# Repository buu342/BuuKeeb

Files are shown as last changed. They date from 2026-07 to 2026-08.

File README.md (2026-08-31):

# BuuKeeb



I've been wanting a decent mechanical keyboard for a while but I've been having a hard time finding something which fit into all of these categories:
- 100% (105 keys)
- ISO Enter
- [QMK](https://qmk.fm/) support
- LED indicators for Caps Lock, Numlock, and Scroll Lock (This one apparently is really difficult to find despite being standard in keyboards for centuries!)

I saw a Glorious PC GMMK Barebones Keyboard for 30€ which seemed to check all of these boxes (including per-key RGB which is a nice to have), but unfortunately the PCB revision I received had a crappy 8-bit MCU, which meant that writing QMK support for it would be infeasible. The case it came with was mostly metal and pretty nice however, so I decided to make a clone of the PCB, but with an STM32. This would also serve as a cool hardware design learning experience for me!

The BuuKeeb™®© features:
- 105 keys with ISO enter for the 0.01% population of the world who types on a Portuguese layout.
- Hotswappable MX switches.
- N-Key Rollover.
- Per Key LEDs on the north side, individually addressible. [OpenRGB](https://openrgb.org/) support. Key colors savable to persistent storage.
- STM32 MCU for QMK support.
- LED indicators for Caps Lock, Numlock, and Scroll Lock (incredible feature, I know).
- My face on the keyboard for added narcissism.
- Functional. Definitely.

### Keyboard Macros:

* **Alt GR + ESC** - Clear the EEPROM
* **Alt GR + F1** - Decrease the screen brightness
* **Alt GR + F2** - Increase the screen brightness
* **Alt GR + F3** - Projection mode (Windows + P)
* **Alt GR + F4** - Open search bar
* **Alt GR + F5** - Previous track
* **Alt GR + F6** - Pause/Play
* **Alt GR + F7** - Next track
* **Alt GR + F8** - Mute
* **Alt GR + F9** - Decrease volume
* **Alt GR + F10** - Increase volume
* **Alt GR + F11** - Decrease backlight brightness
* **Alt GR + F12** - Increase backlight brightness
* **Alt GR + PrntScr** - Mute microphone
* **Alt GR + ScrLck** - Eject disk
* **Alt GR + Pause** - Suspend/Sleep PC
* **CTRL + Alt GR + ESC** - Save OpenRGB Direct Mode colors to persistent memory

### Editing in KiCad

The design uses [marbastlib](https://github.com/ebastler/marbastlib) for some components so make sure you have that installed before opening the project in KiCad.

### Ordering

The `production` folder provides all the files you need for JLCPCB. You can zip up the entire folder and feed it to JLC. 

During the BOM selection, you can refer to the `bom-JLCPCB Assembly Order.xls` file to look at what components I used when I ordered my PCBs.

### Compiling the QMK Firmware:

1. Download the [OpenRGB QMK Community Module](https://gitlab.com/OpenRGBDevelopers/QMK-OpenRGB) repository.
2. Place it inside the `qmk_firmware/modules` folder and rename it to `openrgb`
3. If your copy of the qmk firmware does not ship with a `buukeeb` folder inside the `qmk_firmware/keyboards` folder, copy the QMK folder from my repository and put it inside the `qmk_firmware/keyboards`, renaming it to `buukeeb` (alternatively place a symbolic link instead).
4. Compile the firmware using your preferred method. I am on Linux so I used `qmk compile -kb buukeeb -km default`.
5. To flash the keyboard, hold down the BOOT button on the back of the board (above the 3 status indicator LEDs) and plug it into the PC. You can then let go of the button and flash it using your preferred method. I am on Linux so I used `qmk flash -kb buukeeb -km default`. 

### Special Thanks:

- [BigBass](https://github.com/bigbass1997) for helping me out with a bunch of KiCad questions and reviewing my PCB designs.
- [Keyboard Atelier Discord community](https://kbatelier.org/) for helping me and doing a keyboard review. Specific shoutouts to Quark, Indeed, Moo, The Great Advisor Xaetral™, Sune, and SenseiZéッ for answering general questions. Another big thanks to cadiremar, galile0, Jubakuba, and SenseiZéッ for the keyboard review.
- [QMK Discord community](https://discord.gg/qmk) for helping me bugfix. Specific shoutout to Drashna Jael're for identifying the LED bug.
- [OpenRGB Discord community](https://discord.gg/AQwjJPY) for answering some OpenRGB questions. Specific shoutout to CalcProgrammer1 for answering my questions.

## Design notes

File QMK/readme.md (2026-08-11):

# buukeeb

buukeeb

*A short description of the keyboard/project*

* Keyboard Maintainer: [Lourenço Soares](https://github.com/Buu342)
* Hardware Supported: *The PCBs, controllers supported*
* Hardware Availability: *Links to where you can find this hardware*

Make example for this keyboard (after setting up your build environment):

    make buukeeb:default

Flashing example for this keyboard:

    make buukeeb:default:flash

See the [build environment setup](https://docs.qmk.fm/#/getting_started_build_tools) and the [make instructions](https://docs.qmk.fm/#/getting_started_make_guide) for more information. Brand new to QMK? Start with our [Complete Newbs Guide](https://docs.qmk.fm/#/newbs).

## Bootloader

Enter the bootloader in 3 ways:

* **Bootmagic reset**: Hold down the key at (0,0) in the matrix (usually the top left key or Escape) and plug in the keyboard
* **Physical reset button**: Briefly press the button on the back of the PCB - some may have pads you must short instead
* **Keycode in layout**: Press the key mapped to `QK_BOOT` if it is available

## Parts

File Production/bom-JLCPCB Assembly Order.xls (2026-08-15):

JLCPCB BOM Tool - BOM Matching
BOM name：bom-JLCPCB Assembly Order.xlsx |  |  | Download Time：2026-07-28 05:34:23 |  |  |  | * Our matching results are updated in real-time, but stock and prices may change. If it's been over 24 hours, please re-match before placing your order.
PCB Assembled Qty：5 |  |  | Est. Total Price：35.7558
Your BOM |  |  |  |  | Matched Parts |  |  |  |  |  |  | Order Information
Top Designator | Bottom Designator | Comment | Footprint | JLCPCB Part # | Matches | Part # | Manufacturer | Footprint | Description | Category | Warning | JLCPCB Part # | Product link | Lib Type | Qty | Source | Total Price ($)
 | C1,C10,C100,C101,C102,C103,C104,C105,C106,C107,C108,C109,C11,C110,C111,C112,C113,C114,C115,C116,C117,C118,C12,C13,C14,C15,C16,C17,C18,C19,C2,C20,C21,C22,C23,C24,C25,C26,C27,C28,C29,C3,C30,C31,C32,C33,C34,C35,C36,C37,C38,C39,C4,C40,C41,C42,C43,C44,C45,C46,C47,C48,C49,C5,C50,C51,C52,C53,C54,C55,C56,C57,C58,C59,C6,C60,C61,C62,C63,C64,C65,C66,C67,C68,C69,C70,C71,C72,C73,C74,C75,C76,C77,C78,C79,C80,C81,C82,C83,C84,C85,C86,C87,C88,C89,C90,C91,C92,C93,C94,C95,C96,C97,C98,C99 | 100nF | 0402 |  | Select by System | CL05B104KO5NNNC | Samsung Electro-Mechanics | 0402 | 100nF 16V X7R ±10% 0402 Multilayer Ceramic Capacitors MLCC - SMD/SMT ROHS | Multilayer Ceramic Capacitors MLCC - SMD/SMT |  | C1525 | https://jlcpcb.com/partdetail/1877-CL05B104KO5NNNC/C1525 | Basic | 240 | 240 JLCPCB | 1.272
 | C7 | 10uF | 0603 |  | Select by System | CL10A106KP8NNNC | Samsung Electro-Mechanics | 0603 | 10V 10uF X5R ±10% 0603 Multilayer Ceramic Capacitors MLCC - SMD/SMT ROHS | Multilayer Ceramic Capacitors MLCC - SMD/SMT |  | C19702 | https://jlcpcb.com/partdetail/20411-CL10A106KP8NNNC/C19702 | Basic | 20 | 20 JLCPCB | 0.816
 | C8,C9 | 1uF | 0402 |  | Select by System | CL05A105KA5NQNC | Samsung Electro-Mechanics | 0402 | 1uF 25V X5R ±10% 0402 Multilayer Ceramic Capacitors MLCC - SMD/SMT ROHS | Multilayer Ceramic Capacitors MLCC - SMD/SMT |  | C52923 | https://jlcpcb.com/partdetail/53938-CL05A105KA5NQNC/C52923 | Basic | 20 | 20 JLCPCB | 0.53
 | C119 | 4.7uF | 0603 |  | Select by System | CL10A475KO8NNNC | Samsung Electro-Mechanics | 0603 | 16V 4.7uF X5R ±10% 0603 Multilayer Ceramic Capacitors MLCC - SMD/SMT ROHS | Multilayer Ceramic Capacitors MLCC - SMD/SMT |  | C19666 | https://jlcpcb.com/partdetail/20375-CL10A475KO8NNNC/C19666 | Basic | 20 | 20 JLCPCB | 0.73
 | D1,D10,D100,D101,D102,D103,D104,D105,D11,D12,D13,D14,D15,D16,D17,D18,D19,D2,D20,D21,D22,D23,D24,D25,D26,D27,D28,D29,D3,D30,D31,D32,D33,D34,D35,D36,D37,D38,D39,D4,D40,D41,D42,D43,D44,D45,D46,D47,D48,D49,D5,D50,D51,D52,D53,D54,D55,D56,D57,D58,D59,D6,D60,D61,D62,D63,D64,D65,D66,D67,D68,D69,D7,D70,D71,D72,D73,D74,D75,D76,D77,D78,D79,D8,D80,D81,D82,D83,D84,D85,D86,D87,D88,D89,D9,D90,D91,D92,D93,D94,D95,D96,D97,D98,D99 | D | D_SOD-123 |  | Select by Customer | 1N4148SOD-123 | Shenzhen Jinkaisheng Elec | SOD-123 | -65℃~+150℃@(Tj) 150mA 1V@10mA 2A 400mW 4ns 5uA@75V 75V Independent SOD-123 Switching Diodes ROHS | Switching Diodes |  | C2972760 | https://jlcpcb.com/partdetail/3368026-1N4148SOD123/C2972760 | Extended | 220 | 220 JLCPCB | 2.794
 | F1 | 500mA | 1206 |  | Select by System | BSMD1206-050-33V | BHFUSE | 1206 | -40℃~+85℃ 1.9mm 150mΩ 1A 1mm 3.6mm 33V 40A 500mA 800mW 850mΩ 1206 Resettable Fuses ROHS | Resettable Fuses |  | C7202014 | https://jlcpcb.com/partdetail/BHFUSE-BSMD1206_05033V/C7202014 | Extended | 6 | 6 JLCPCB | 0.4116
 | J2 | Conn_01x05_Pin | PinHeader_1x05_P2.00mm_Horizontal |  | Select by Customer | PZ200-1-05-W-2.0-G1 | HCTL | 弯插,P=2mm | -40℃~+105℃ 1 1.5A 1x5P 2mm 2mm 4mm 5P Black Brass Gold Pin Header Right Angle Push-Pull,P=2mm Pin Headers ROHS | Pin Headers |  | C19270575 | https://jlcpcb.com/partdetail/HCTL-PZ200_1_05_W_2_0G1/C19270575 | Extended | 2 | 2 JLCPCB | 0.1626
 | LED1,LED10,LED100,LED101,LED102,LED103,LED104,LED105,LED106,LED107,LED108,LED11,LED12,LED13,LED14,LED15,LED16,LED17,LED18,LED19,LED2,LED20,LED21,LED22,LED23,LED24,LED25,LED26,LED27,LED28,LED29,LED3,LED30,LED31,LED32,LED33,LED34,LED35,LED36,LED37,LED38,LED39,LED4,LED40,LED41,LED42,LED43,LED44,LED45,LED46,LED47,LED48,LED49,LED5,LED50,LED51,LED52,LED53,LED54,LED55,LED56,LED57,LED58,LED59,LED6,LED60,LED61,LED62,LED63,LED64,LED65,LED66,LED67,LED68,LED69,LED7,LED70,LED71,LED72,LED73,LED74,LED75,LED76,LED77,LED78,LED79,LED8,LED80,LED81,LED82,LED83,LED84,LED85,LED86,LED87,LED88,LED89,LED9,LED90,LED91,LED92,LED93,LED94,LED95,LED96,LED97,LED98,LED99 | SK6812MINI-E | LED_6028R_NoHoles |  | Select by System | SK6812MINI-E | OPSCO Optoelectronics | SMD | -40℃~+85℃ 0.6mA 1.78mm 120° 1kHz 2.8mm 2000V 3.2mm 3.7V~5.5V 800Kbit/s G:815mcd~1275mcd、B:120mcd~240mcd、R:160mcd~320mcd R:620nm~625nm、G:515nm~525nm、B:460nm~470nm Semi-transparent lens SMD RGB LEDs(Built-in IC) ROHS | RGB LEDs(Built-In IC) |  | C5149201 | https://jlcpcb.com/partdetail/OPSCOOptoelectronics-SK6812MINIE/C5149201 | Extended | 218 | 218 JLCPCB | 13.08
 | MX1,MX10,MX100,MX101,MX102,MX103,MX104,MX105,MX11,MX12,MX13,MX14,MX15,MX16,MX17,MX18,MX19,MX2,MX20,MX21,MX22,MX23,MX24,MX25,MX26,MX27,MX28,MX29,MX3,MX30,MX31,MX32,MX33,MX34,MX35,MX36,MX37,MX38,MX39,MX4,MX40,MX41,MX42,MX43,MX44,MX45,MX46,MX47,MX48,MX49,MX5,MX50,MX51,MX52,MX53,MX54,MX55,MX56,MX57,MX58,MX59,MX6,MX60,MX61,MX62,MX63,MX64,MX65,MX66,MX67,MX68,MX69,MX7,MX70,MX71,MX72,MX73,MX74,MX75,MX76,MX77,MX78,MX79,MX8,MX80,MX81,MX82,MX83,MX84,MX85,MX86,MX87,MX88,MX89,MX9,MX90,MX91,MX92,MX93,MX94,MX95,MX96,MX97,MX98,MX99 | MX_SW_HS | SW_MX_HS_CPG151101S11_1.5u_NoHoles |  | Select by Customer | CPG151101S11-2 | HanElectricity | - | 12V 2 3000gf 5,000 cycles - Mechanical Keyboard Shaft ROHS |  |  | C49352235 | https://jlcpcb.com/partdetail/HanElectricity-CPG151101S112/C49352235 | Extended | 210 | 210 JLCPCB | 7.602
 | R1,R4 | 5.1k | 0402 |  | Unconfirmed | 0402WGF5101TCE | UNI-ROYAL(Uniroyal Elec) | 0402 | -55℃~+155℃ 5.1kΩ 50V 62.5mW Thick Film Resistor ±1% ±100ppm/℃ 0402 Chip Resistor - Surface Mount ROHS | Chip Resistor - Surface Mount | 1.The comment (0402WGF5101TCE) of this part does not match the one (5.1k) provided in your BOM. Please confirm; | C25905 | https://jlcpcb.com/partdetail/26648-0402WGF5101TCE/C25905 | Basic | 20 | 20 JLCPCB | 0.134
 | R2 | 470 | 0402 |  | Unconfirmed | 0402WGF4700TCE | UNI-ROYAL(Uniroyal Elec) | 0402 | -55℃~+155℃ 470Ω 50V 62.5mW Thick Film Resistor ±1% ±100ppm/℃ 0402 Chip Resistor - Surface Mount ROHS | Chip Resistor - Surface Mount | 1.The comment (0402WGF4700TCE) of this part does not match the one (470) provided in your BOM. Please confirm; | C25117 | https://jlcpcb.com/partdetail/25860-0402WGF4700TCE/C25117 | Basic | 20 | 20 JLCPCB | 0.154
 | SW1 | SW_Push | SW_SPST_TL3342 |  | Select by System | TS-1187A-B-A-B | XKB Connection | SMD-4P,5.1x5.1mm | -30℃~+85℃ 1.5mm 1.6N 100,000 cycles 12V 5.1mm 5.1mm 50mA Gold No Round Button SPST Surface Mount,Vertical Without Bracket SMD-4P,5.1x5.1mm Tactile Switches ROHS | Tactile Switches |  | C318884 | https://jlcpcb.com/partdetail/XKBConnection-TS_1187A_B_AB/C318884 | Basic | 7 | 7 JLCPCB | 0.1428
 | U1 | STM32F072C8Tx | LQFP-48_7x7mm_P0.5mm |  | Select by Customer | STM32F072C8T6 | STMicroelectronics | LQFP-48(7x7) | -40℃~+85℃ 1.65V~3.6V 12bit 12bit 16KB 32 Bit 37 48MHz 64KB ARM Cortex-M0 Built-in FLASH LQFP-48(7x7) Microcontrollers (MCU/MPU/SOC) ROHS | Microcontrollers (MCU/MPU/SOC) |  | C80488 | https://jlcpcb.com/partdetail/STMicroelectronics-STM32F072C8T6/C80488 | Extended | 2 | 2 JLCPCB | 5.0882
 | U2 | 74AHCT1G125 | TSOP-5_1.65x3.05mm_P0.95mm |  | Select by Customer | 74AHCT1G125GV | MDD(Microdiode Semiconductor) | SOT-23-5L | -40℃~+125℃ 1 1 1ns@4.5V 4.5V~5.5V 40uA 74AHCT 8mA 8mA Output enable、Level shifting Tri-State Unidirectional SOT-23-5L Buffers, Drivers, Receivers, Transceivers ROHS |  |  | C52140417 | https://jlcpcb.com/partdetail/54938146-74AHCT1G125GV/C52140417 | Extended | 6 | 6 JLCPCB | 0.3889
 | U3 | XC6206PxxxMR | SOT-23-3 |  | Select by Customer | XC6206P332MR-G | Torex Semicon | SOT-23-3L | -40℃~+85℃@(Ta) 1 1uA 200mA 3.3V 6V Fixed Over Current Protection Positive SOT-23-3L Voltage Regulators - Linear, Low Drop Out (LDO) Regulators ROHS | Voltage Regulators - Linear, Low Drop Out (LDO) Regulators |  | C5446 | https://jlcpcb.com/partdetail/TorexSemicon-XC6206P332MRG/C5446 | Basic | 5 | 5 JLCPCB | 0.663
 | U4 | USB6B1 | SOIC-8_3.9x4.9mm_P1.27mm |  | Select by Customer | USB6B1RL | STMicroelectronics | SOIC-8 | 10uA 15pF、25pF 2 25A@8/20us 5.25V 500W@8/20us 6V Bidirectional IEC 61000-4-2 TVS SOIC-8 ESD and Surge Protection (TVS/ESD) ROHS | ESD And Surge Protection (TVS/ESD) | 1.The comment (USB6B1RL) of this part does not match the one (USB6B1) provided in your BOM. Please confirm; | C10508 | https://jlcpcb.com/partdetail/STMicroelectronics-USB6B1RL/C10508 | Extended | 2 | 2 JLCPCB | 1.7478

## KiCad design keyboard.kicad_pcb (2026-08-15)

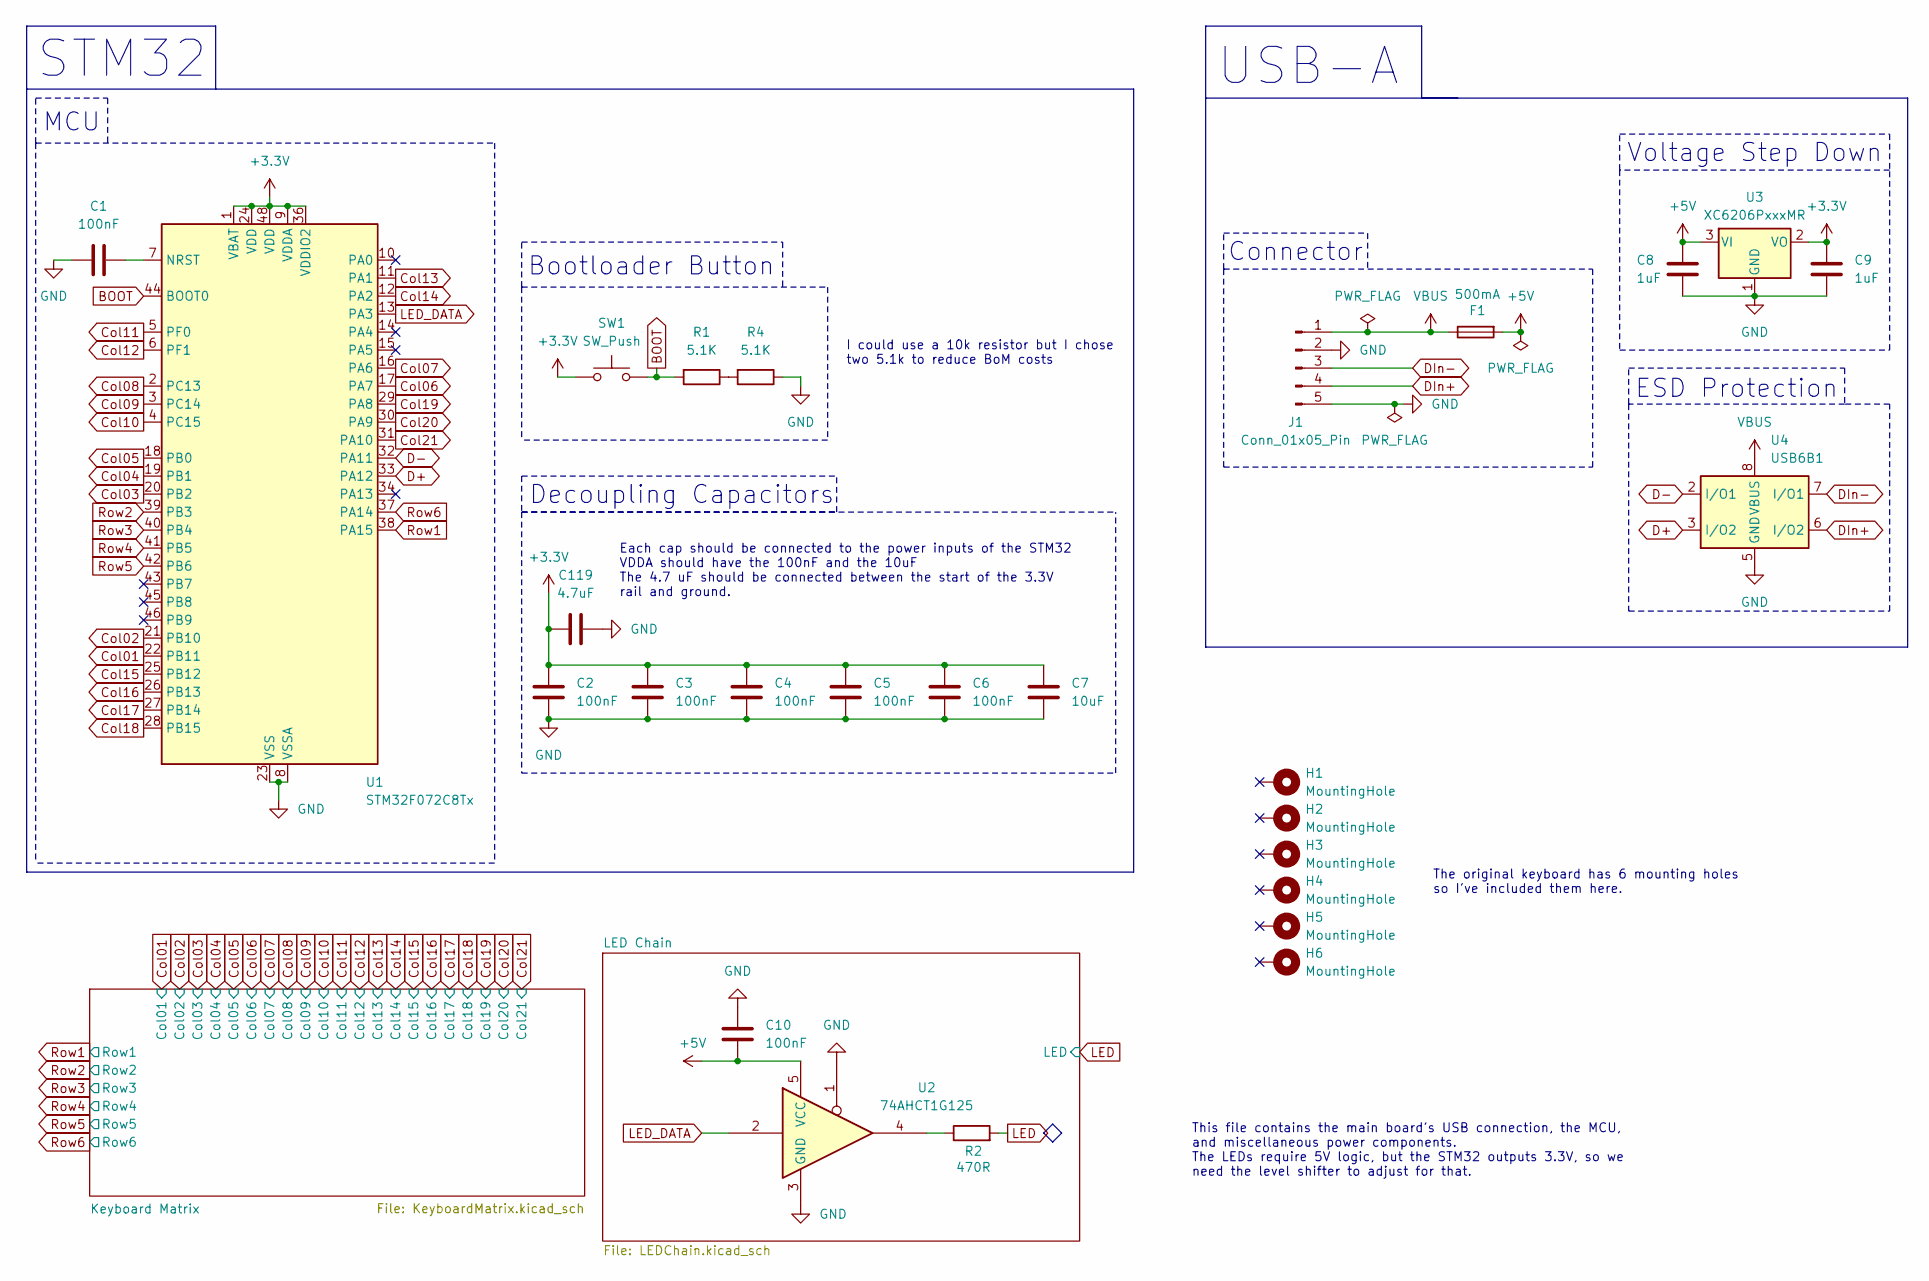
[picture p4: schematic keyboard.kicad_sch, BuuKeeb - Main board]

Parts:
C1, C2, C3, C4, C5, C6, C10: 100nF; C_0402_1005Metric
C7: 10uF; C_0603_1608Metric
C8, C9: 1uF; C_0603_1608Metric
C119: 4.7uF; C_0603_1608Metric
F1: 500mA; Fuse_1206_3216Metric
H1, H2, H3, H4, H5, H6: MountingHole; MountingHole_3.5mm_Pad_5.5mm
J1: Conn_01x05_Pin; PinHeader_1x05_P2.00mm_Horizontal
R1, R4: 5.1K; R_0402_1005Metric
R2: 470R; R_0402_1005Metric
SW1: SW_Push; SW_SPST_TL3342
U1: STM32F072C8Tx; LQFP-48_7x7mm_P0.5mm
U2: 74AHCT1G125; TSOP-5_1.65x3.05mm_P0.95mm
U3: XC6206PxxxMR; SOT-23-3
U4: USB6B1; SOIC-8_3.9x4.9mm_P1.27mm

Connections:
+3.3V: C2.1, C3.1, C4.1, C5.1, C6.1, C7.1, C9.1, C119.1, SW1.1, U1.1 (VBAT), U1.9 (VDDA), U1.24 (VDD), U1.36 (VDDIO2), U1.48 (VDD), U3.2 (VO)
+5V: C8.1, C10.2, F1.2, U2.5 (VCC), U3.3 (VI); also elsewhere on the board
BOOT: R1.2, SW1.2, U1.44 (BOOT0)
Col01: U1.22 (PB11); also elsewhere on the board
Col02: U1.21 (PB10); also elsewhere on the board
Col03: U1.20 (PB2); also elsewhere on the board
Col04: U1.19 (PB1); also elsewhere on the board
Col05: U1.18 (PB0); also elsewhere on the board
Col06: U1.17 (PA7); also elsewhere on the board
Col07: U1.16 (PA6); also elsewhere on the board
Col08: U1.2 (PC13); also elsewhere on the board
Col09: U1.3 (PC14); also elsewhere on the board
Col10: U1.4 (PC15); also elsewhere on the board
Col11: U1.5 (PF0); also elsewhere on the board
Col12: U1.6 (PF1); also elsewhere on the board
Col13: U1.11 (PA1); also elsewhere on the board
Col14: U1.12 (PA2); also elsewhere on the board
Col15: U1.25 (PB12); also elsewhere on the board
Col16: U1.26 (PB13); also elsewhere on the board
Col17: U1.27 (PB14); also elsewhere on the board
Col18: U1.28 (PB15); also elsewhere on the board
Col19: U1.29 (PA8); also elsewhere on the board
Col20: U1.30 (PA9); also elsewhere on the board
Col21: U1.31 (PA10); also elsewhere on the board
D+: U1.33 (PA12), U4.3 (I/O2)
D-: U1.32 (PA11), U4.2 (I/O1)
DIn+: J1.4, U4.6 (I/O2)
DIn-: J1.3, U4.7 (I/O1)
GND: C1.2, C2.2, C3.2, C4.2, C5.2, C6.2, C7.2, C8.2, C9.2, C10.1, C119.2, J1.2, J1.5, R4.1, U1.8 (VSSA), U1.23 (VSS), U1.35 (VSS), U1.47 (VSS), U2.1, U2.3 (GND), U3.1 (GND), U4.4 (GND), U4.5 (GND); also elsewhere on the board
LED: R2.2; also elsewhere on the board
LED_DATA: U1.13 (PA3), U2.2
unnamed: R1.1, R4.2
unnamed: R2.1, U2.4
unnamed: C1.1, U1.7 (NRST)
Row1: U1.38 (PA15); also elsewhere on the board
Row2: U1.39 (PB3); also elsewhere on the board
Row3: U1.40 (PB4); also elsewhere on the board
Row4: U1.41 (PB5); also elsewhere on the board
Row5: U1.42 (PB6); also elsewhere on the board
Row6: U1.37 (PA14); also elsewhere on the board
VBUS: F1.1, J1.1, U4.1 (VBUS), U4.8 (VBUS)

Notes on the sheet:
Connector
Voltage Step Down
MCU
The original keyboard has 6 mounting holes so I've included them here.
STM32
ESD Protection
Decoupling Capacitors
This file contains the main board's USB connection, the MCU, and miscellaneous power components. The LEDs require 5V logic, but the STM32 outputs 3.3V, so we need the level shifter to adjust for that.
I could use a 10k resistor but I chose two 5.1k to reduce BoM costs
USB-A
Bootloader Button
Each cap should be connected to the power inputs of the STM32 VDDA should have the 100nF and the 10uF The 4.7 uF should be connected between the start of the 3.3V rail and ground.

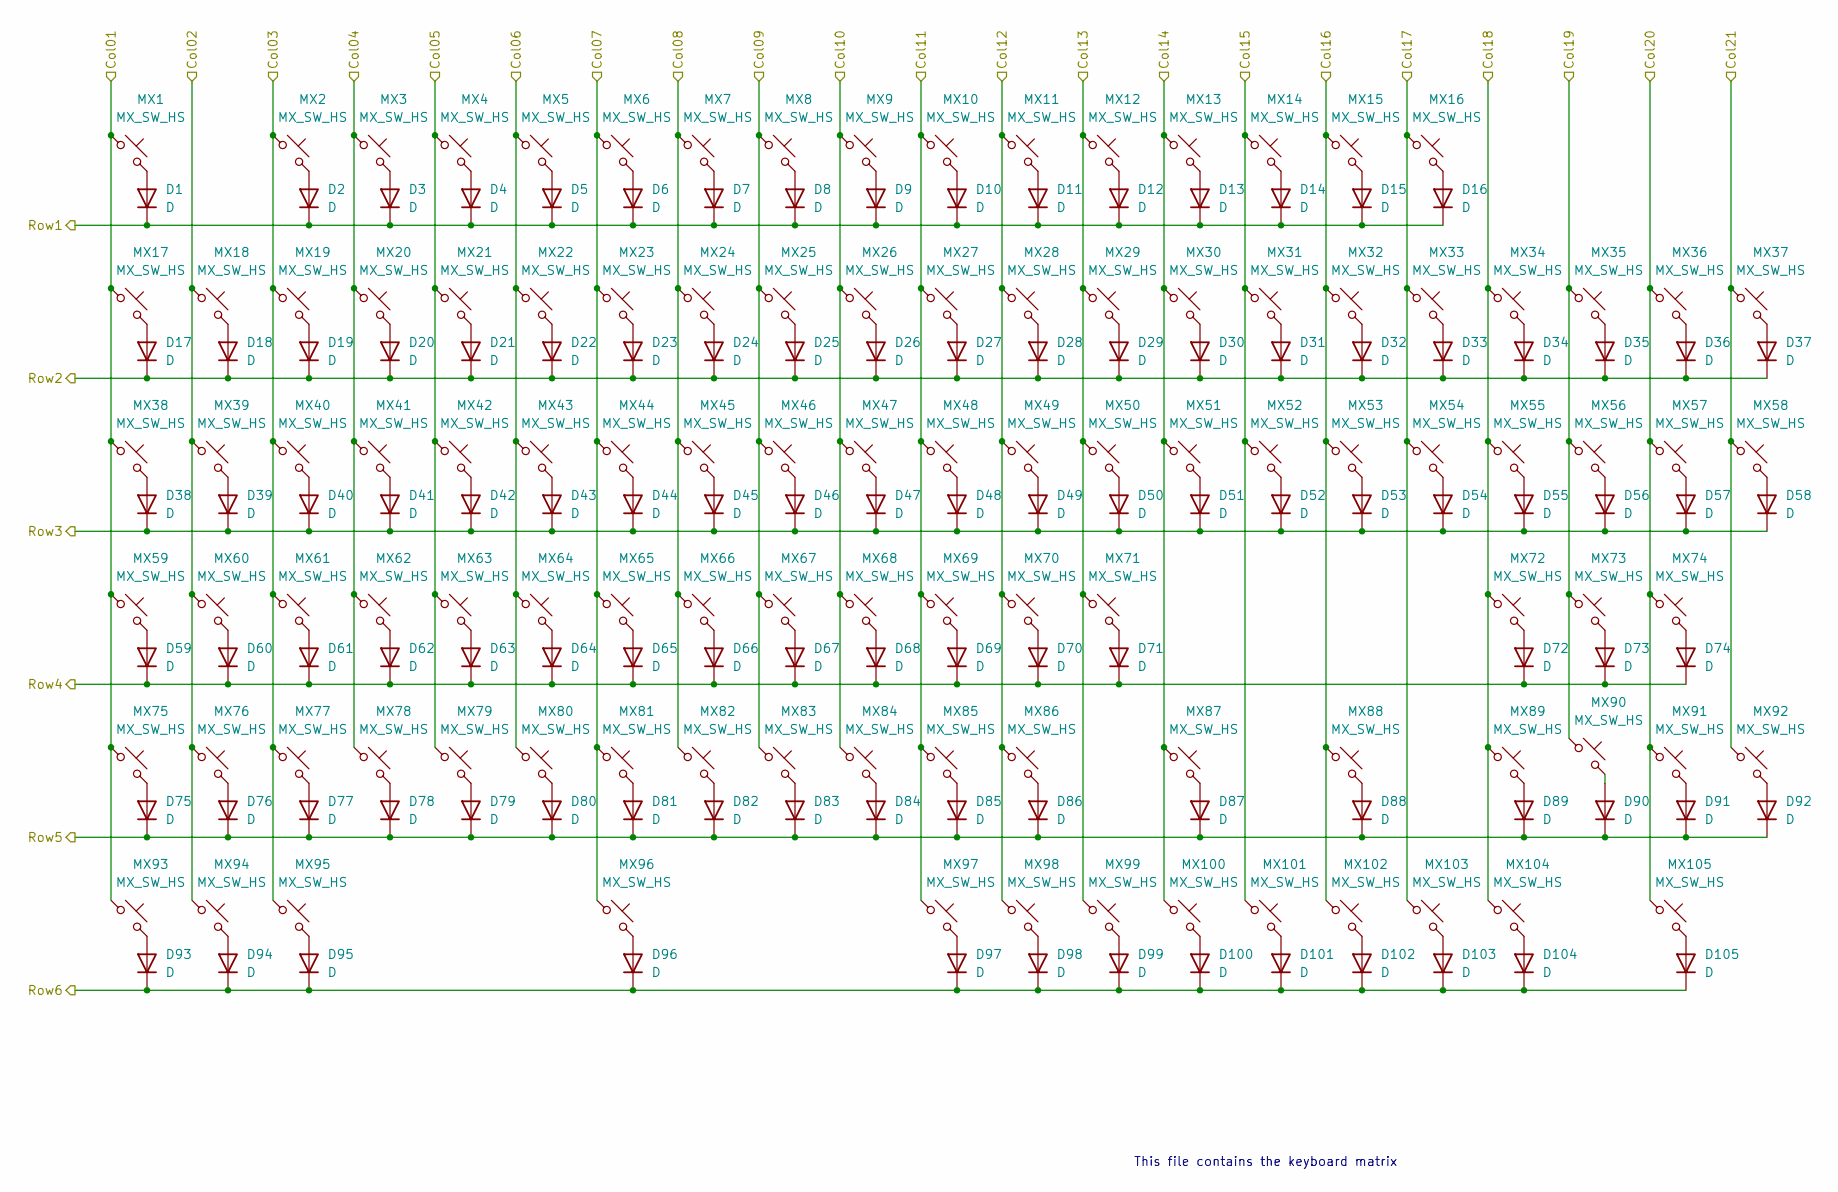
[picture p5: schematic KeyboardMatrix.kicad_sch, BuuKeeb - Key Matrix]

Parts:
D1, D2, D3, D4, D5, D6, D7, D8, D9, D10, D11, D12, D13, D14, D15, D16, D17, D18, D19, D20, D21, D22, D23, D24, D25, D26, D27, D28, D29, D30, D31, D32, D33, D34, D35, D36, D37, D38, D39, D40, D41, D42, D43, D44, D45, D46, D47, D48, D49, D50, D51, D52, D53, D54, D55, D56, D57, D58, D59, D60, D61, D62, D63, D64, D65, D66, D67, D68, D69, D70, D71, D72, D73, D74, D75, D76, D77, D78, D79, D80, D81, D82, D83, D84, D85, D86, D87, D88, D89, D90, D91, D92, D93, D94, D95, D96, D97, D98, D99, D100, D101, D102, D103, D104, D105: D; D_SOD-123
MX1, MX2, MX3, MX4, MX5, MX6, MX7, MX8, MX9, MX10, MX11, MX12, MX13, MX14, MX15, MX16, MX17, MX18, MX19, MX20, MX21, MX22, MX23, MX24, MX25, MX26, MX27, MX28, MX29, MX30, MX31, MX32, MX33, MX34, MX35, MX36, MX37, MX38, MX39, MX40, MX41, MX42, MX43, MX44, MX45, MX46, MX47, MX48, MX49, MX50, MX51, MX52, MX53, MX54, MX55, MX56, MX57, MX58, MX59, MX60, MX61, MX62, MX63, MX64, MX65, MX66, MX67, MX68, MX69, MX70, MX71, MX72, MX73, MX74, MX75, MX76, MX77, MX78, MX79, MX80, MX81, MX82, MX83, MX84, MX85, MX86, MX87, MX88, MX89, MX90, MX91, MX92, MX93, MX94, MX95, MX96, MX97, MX98, MX99, MX100, MX101, MX102, MX103, MX104, MX105: MX_SW_HS; SW_MX_HS_CPG151101S11_1.5u_NoHoles

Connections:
Col01: MX1.1, MX17.1, MX38.1, MX59.1, MX75.1, MX93.1; also elsewhere on the board
Col02: MX18.1, MX39.1, MX60.1, MX76.1, MX94.1; also elsewhere on the board
Col03: MX2.1, MX19.1, MX40.1, MX61.1, MX77.1, MX95.1; also elsewhere on the board
Col04: MX3.1, MX20.1, MX41.1, MX62.1, MX78.1; also elsewhere on the board
Col05: MX4.1, MX21.1, MX42.1, MX63.1, MX79.1; also elsewhere on the board
Col06: MX5.1, MX22.1, MX43.1, MX64.1, MX80.1; also elsewhere on the board
Col07: MX6.1, MX23.1, MX44.1, MX65.1, MX81.1, MX96.1; also elsewhere on the board
Col08: MX7.1, MX24.1, MX45.1, MX66.1, MX82.1; also elsewhere on the board
Col09: MX8.1, MX25.1, MX46.1, MX67.1, MX83.1; also elsewhere on the board
Col10: MX9.1, MX26.1, MX47.1, MX68.1, MX84.1; also elsewhere on the board
Col11: MX10.1, MX27.1, MX48.1, MX69.1, MX85.1, MX97.1; also elsewhere on the board
Col12: MX11.1, MX28.1, MX49.1, MX70.1, MX86.1, MX98.1; also elsewhere on the board
Col13: MX12.1, MX29.1, MX50.1, MX71.1, MX99.1; also elsewhere on the board
Col14: MX13.1, MX30.1, MX51.1, MX87.1, MX100.1; also elsewhere on the board
Col15: MX14.1, MX31.1, MX52.1, MX101.1; also elsewhere on the board
Col16: MX15.1, MX32.1, MX53.1, MX88.1, MX102.1; also elsewhere on the board
Col17: MX16.1, MX33.1, MX54.1, MX103.1; also elsewhere on the board
Col18: MX34.1, MX55.1, MX72.1, MX89.1, MX104.1; also elsewhere on the board
Col19: MX35.1, MX56.1, MX73.1, MX90.1; also elsewhere on the board
Col20: MX36.1, MX57.1, MX74.1, MX91.1, MX105.1; also elsewhere on the board
Col21: MX37.1, MX58.1, MX92.1; also elsewhere on the board
unnamed: D1.2 (A), MX1.2
unnamed: D2.2 (A), MX2.2
unnamed: D3.2 (A), MX3.2
unnamed: D4.2 (A), MX4.2
unnamed: D5.2 (A), MX5.2
unnamed: D6.2 (A), MX6.2
unnamed: D7.2 (A), MX7.2
unnamed: D8.2 (A), MX8.2
unnamed: D9.2 (A), MX9.2
unnamed: D10.2 (A), MX10.2
unnamed: D11.2 (A), MX11.2
unnamed: D12.2 (A), MX12.2
unnamed: D13.2 (A), MX13.2
unnamed: D14.2 (A), MX14.2
unnamed: D15.2 (A), MX15.2
unnamed: D16.2 (A), MX16.2
unnamed: D17.2 (A), MX17.2
unnamed: D18.2 (A), MX18.2
unnamed: D19.2 (A), MX19.2
unnamed: D20.2 (A), MX20.2
unnamed: D21.2 (A), MX21.2
unnamed: D22.2 (A), MX22.2
unnamed: D23.2 (A), MX23.2
unnamed: D24.2 (A), MX24.2
unnamed: D25.2 (A), MX25.2
unnamed: D26.2 (A), MX26.2
unnamed: D27.2 (A), MX27.2
unnamed: D28.2 (A), MX28.2
unnamed: D29.2 (A), MX29.2
unnamed: D30.2 (A), MX30.2
unnamed: D31.2 (A), MX31.2
unnamed: D32.2 (A), MX32.2
unnamed: D33.2 (A), MX33.2
unnamed: D34.2 (A), MX34.2
unnamed: D35.2 (A), MX35.2
unnamed: D36.2 (A), MX36.2
unnamed: D37.2 (A), MX37.2
unnamed: D38.2 (A), MX38.2
unnamed: D39.2 (A), MX39.2
unnamed: D40.2 (A), MX40.2
unnamed: D41.2 (A), MX41.2
unnamed: D42.2 (A), MX42.2
unnamed: D43.2 (A), MX43.2
unnamed: D44.2 (A), MX44.2
unnamed: D45.2 (A), MX45.2
unnamed: D46.2 (A), MX46.2
unnamed: D47.2 (A), MX47.2
unnamed: D48.2 (A), MX48.2
unnamed: D49.2 (A), MX49.2
unnamed: D50.2 (A), MX50.2
unnamed: D51.2 (A), MX51.2
unnamed: D52.2 (A), MX52.2
unnamed: D53.2 (A), MX53.2
unnamed: D54.2 (A), MX54.2
unnamed: D55.2 (A), MX55.2
unnamed: D56.2 (A), MX56.2
unnamed: D57.2 (A), MX57.2
unnamed: D58.2 (A), MX58.2
unnamed: D59.2 (A), MX59.2
unnamed: D60.2 (A), MX60.2
unnamed: D61.2 (A), MX61.2
unnamed: D62.2 (A), MX62.2
unnamed: D63.2 (A), MX63.2
unnamed: D64.2 (A), MX64.2
unnamed: D65.2 (A), MX65.2
unnamed: D66.2 (A), MX66.2
unnamed: D67.2 (A), MX67.2
unnamed: D68.2 (A), MX68.2
unnamed: D69.2 (A), MX69.2
unnamed: D70.2 (A), MX70.2
unnamed: D71.2 (A), MX71.2
unnamed: D72.2 (A), MX72.2
unnamed: D73.2 (A), MX73.2
unnamed: D74.2 (A), MX74.2
unnamed: D75.2 (A), MX75.2
unnamed: D76.2 (A), MX76.2
unnamed: D77.2 (A), MX77.2
unnamed: D78.2 (A), MX78.2
unnamed: D79.2 (A), MX79.2
unnamed: D80.2 (A), MX80.2
unnamed: D81.2 (A), MX81.2
unnamed: D82.2 (A), MX82.2
unnamed: D83.2 (A), MX83.2
unnamed: D84.2 (A), MX84.2
unnamed: D85.2 (A), MX85.2
unnamed: D86.2 (A), MX86.2
unnamed: D87.2 (A), MX87.2
unnamed: D88.2 (A), MX88.2
unnamed: D89.2 (A), MX89.2
unnamed: D90.2 (A), MX90.2
unnamed: D91.2 (A), MX91.2
unnamed: D92.2 (A), MX92.2
unnamed: D93.2 (A), MX93.2
unnamed: D94.2 (A), MX94.2
unnamed: D95.2 (A), MX95.2
unnamed: D96.2 (A), MX96.2
unnamed: D97.2 (A), MX97.2
unnamed: D98.2 (A), MX98.2
unnamed: D99.2 (A), MX99.2
unnamed: D100.2 (A), MX100.2
unnamed: D101.2 (A), MX101.2
unnamed: D102.2 (A), MX102.2
unnamed: D103.2 (A), MX103.2
unnamed: D104.2 (A), MX104.2
unnamed: D105.2 (A), MX105.2
Row1: D1.1 (K), D2.1 (K), D3.1 (K), D4.1 (K), D5.1 (K), D6.1 (K), D7.1 (K), D8.1 (K), D9.1 (K), D10.1 (K), D11.1 (K), D12.1 (K), D13.1 (K), D14.1 (K), D15.1 (K), D16.1 (K); also elsewhere on the board
Row2: D17.1 (K), D18.1 (K), D19.1 (K), D20.1 (K), D21.1 (K), D22.1 (K), D23.1 (K), D24.1 (K), D25.1 (K), D26.1 (K), D27.1 (K), D28.1 (K), D29.1 (K), D30.1 (K), D31.1 (K), D32.1 (K), D33.1 (K), D34.1 (K), D35.1 (K), D36.1 (K), D37.1 (K); also elsewhere on the board
Row3: D38.1 (K), D39.1 (K), D40.1 (K), D41.1 (K), D42.1 (K), D43.1 (K), D44.1 (K), D45.1 (K), D46.1 (K), D47.1 (K), D48.1 (K), D49.1 (K), D50.1 (K), D51.1 (K), D52.1 (K), D53.1 (K), D54.1 (K), D55.1 (K), D56.1 (K), D57.1 (K), D58.1 (K); also elsewhere on the board
Row4: D59.1 (K), D60.1 (K), D61.1 (K), D62.1 (K), D63.1 (K), D64.1 (K), D65.1 (K), D66.1 (K), D67.1 (K), D68.1 (K), D69.1 (K), D70.1 (K), D71.1 (K), D72.1 (K), D73.1 (K), D74.1 (K); also elsewhere on the board
Row5: D75.1 (K), D76.1 (K), D77.1 (K), D78.1 (K), D79.1 (K), D80.1 (K), D81.1 (K), D82.1 (K), D83.1 (K), D84.1 (K), D85.1 (K), D86.1 (K), D87.1 (K), D88.1 (K), D89.1 (K), D90.1 (K), D91.1 (K), D92.1 (K); also elsewhere on the board
Row6: D93.1 (K), D94.1 (K), D95.1 (K), D96.1 (K), D97.1 (K), D98.1 (K), D99.1 (K), D100.1 (K), D101.1 (K), D102.1 (K), D103.1 (K), D104.1 (K), D105.1 (K); also elsewhere on the board

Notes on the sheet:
This file contains the keyboard matrix

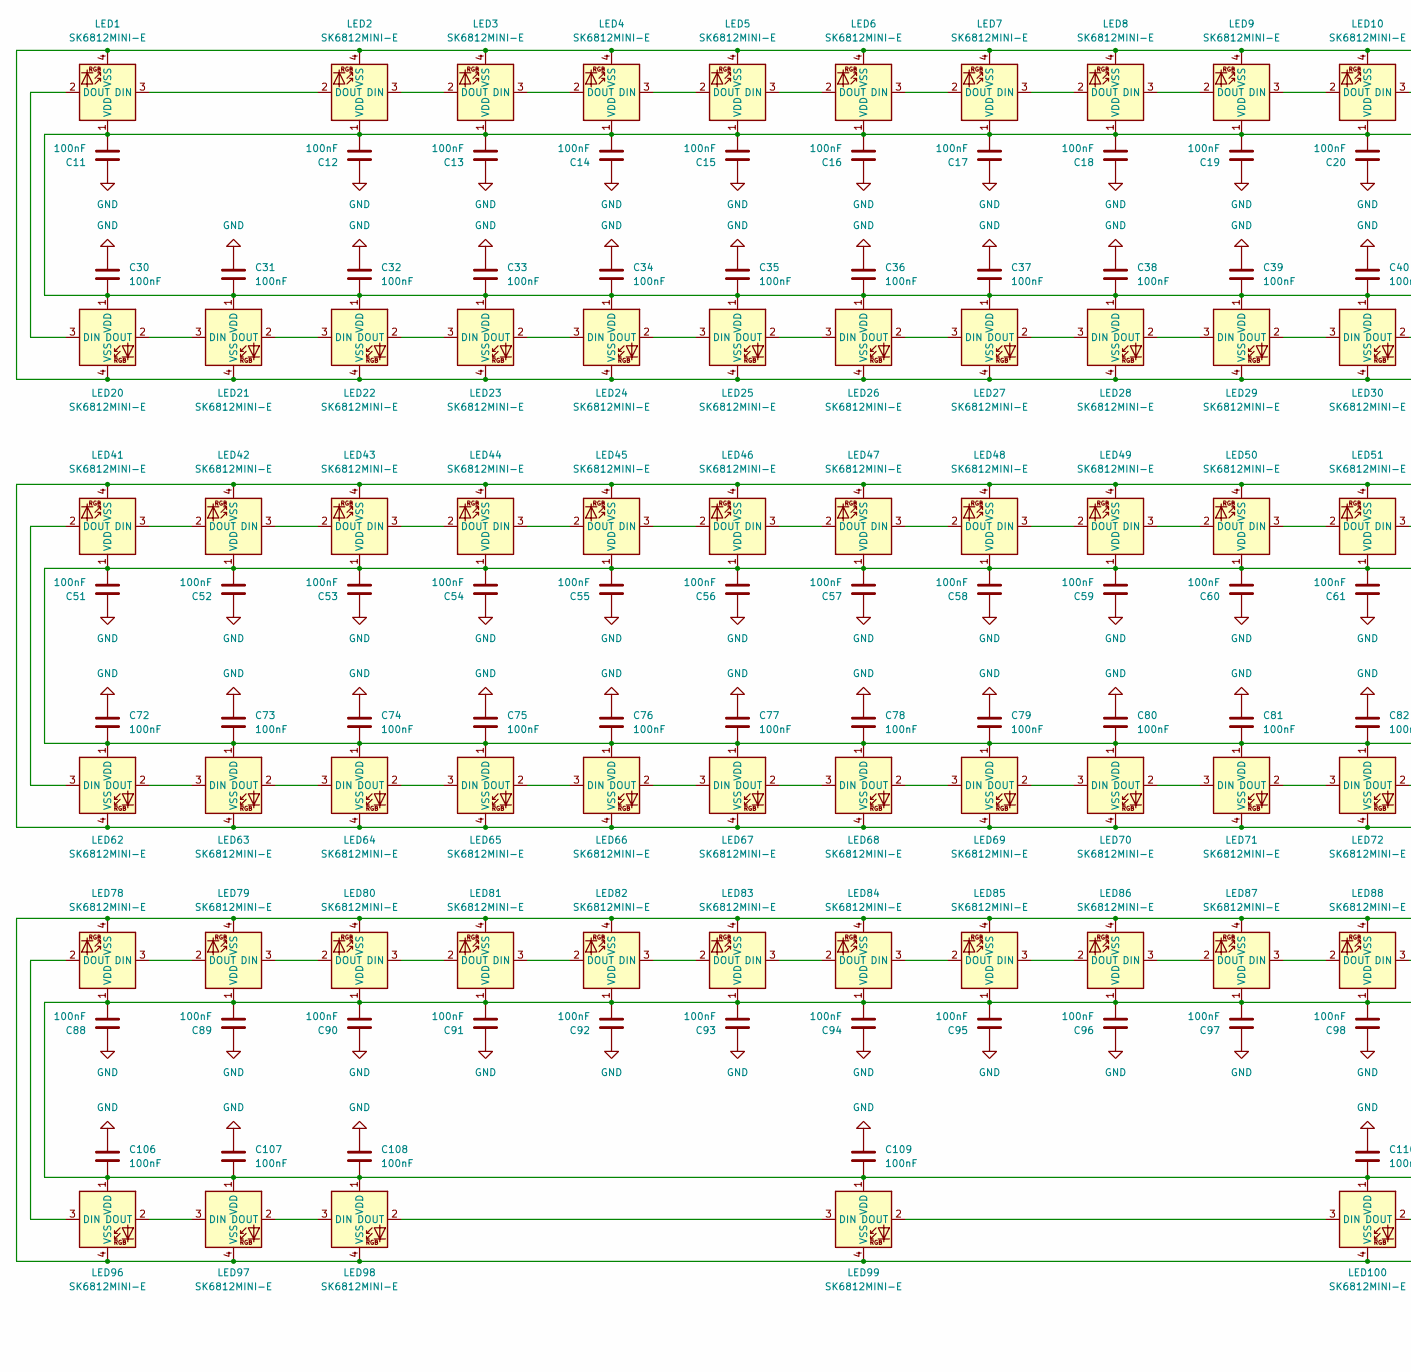
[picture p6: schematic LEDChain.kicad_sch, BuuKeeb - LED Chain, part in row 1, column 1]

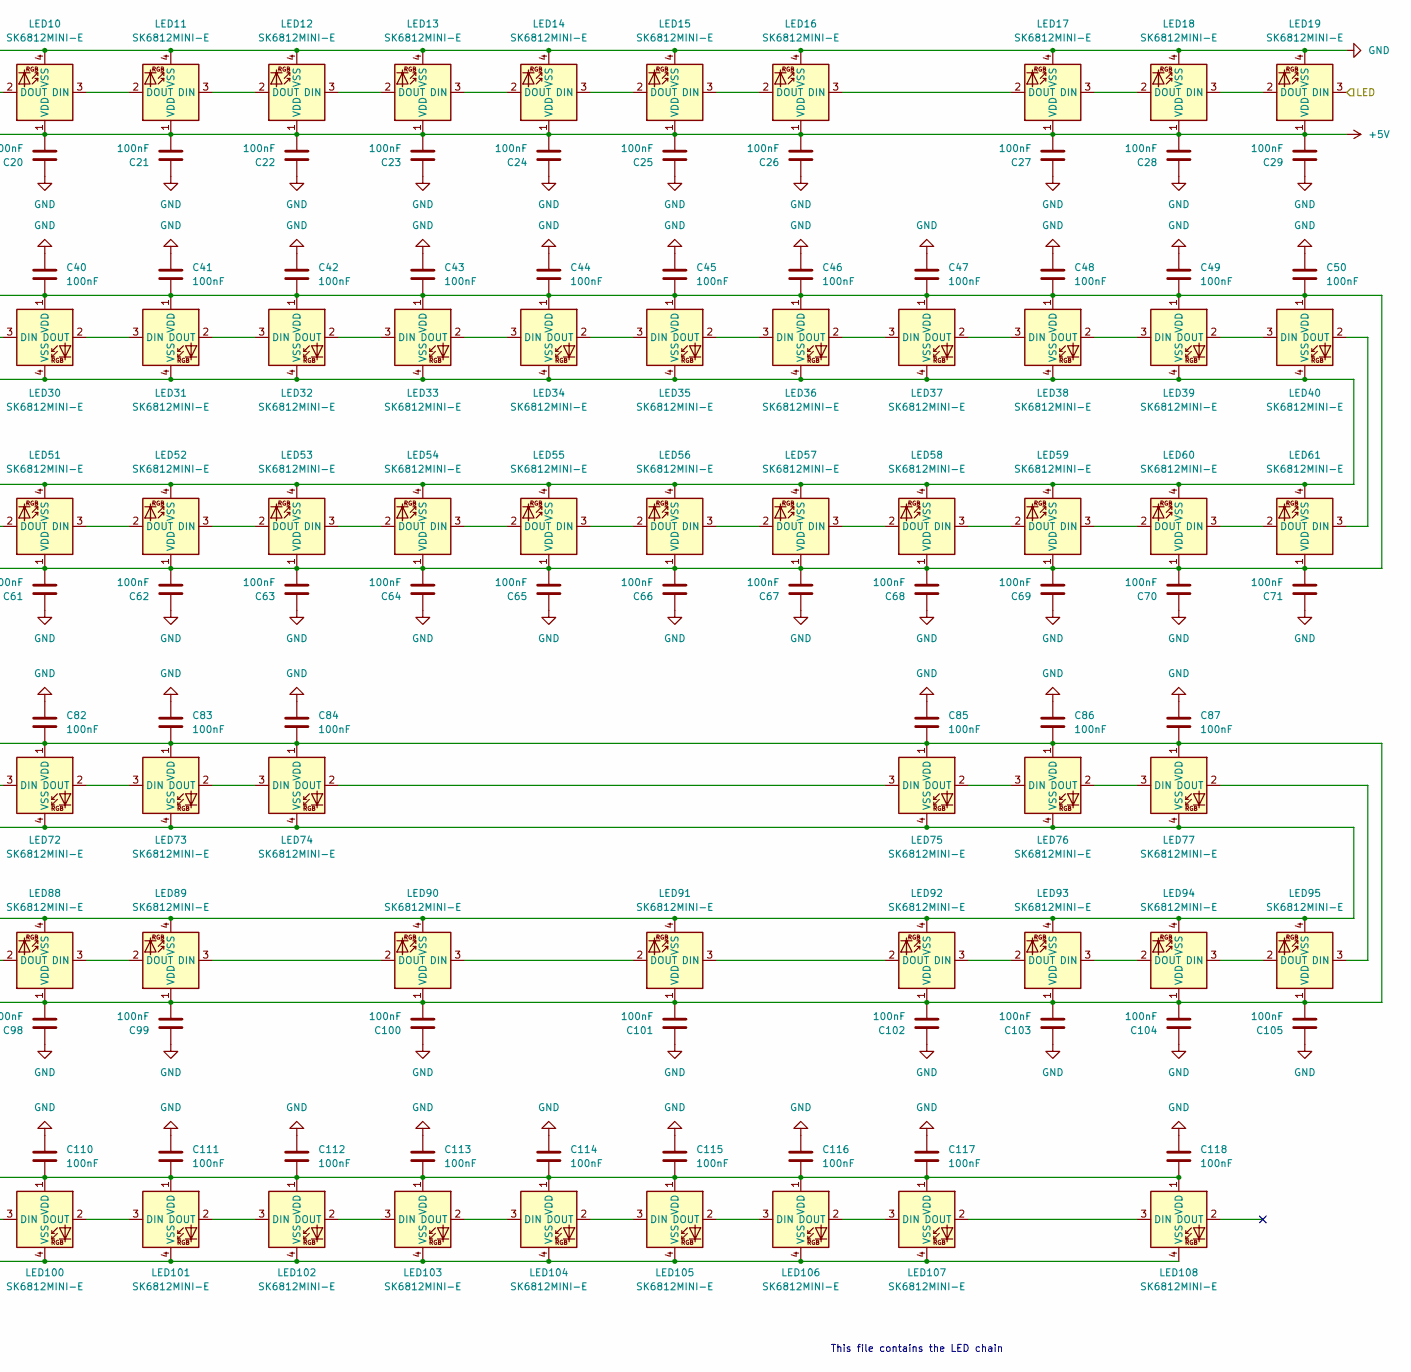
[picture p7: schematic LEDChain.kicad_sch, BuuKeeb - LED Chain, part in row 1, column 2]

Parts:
C11, C12, C13, C14, C15, C16, C17, C18, C19, C20, C21, C22, C23, C24, C25, C26, C27, C28, C29, C30, C31, C32, C33, C34, C35, C36, C37, C38, C39, C40, C41, C42, C43, C44, C45, C46, C47, C48, C49, C50, C51, C52, C53, C54, C55, C56, C57, C58, C59, C60, C61, C62, C63, C64, C65, C66, C67, C68, C69, C70, C71, C72, C73, C74, C75, C76, C77, C78, C79, C80, C81, C82, C83, C84, C85, C86, C87, C88, C89, C90, C91, C92, C93, C94, C95, C96, C97, C98, C99, C100, C101, C102, C103, C104, C105, C106, C107, C108, C109, C110, C111, C112, C113, C114, C115, C116, C117, C118: 100nF; C_0402_1005Metric
LED1, LED2, LED3, LED4, LED5, LED6, LED7, LED8, LED9, LED10, LED11, LED12, LED13, LED14, LED15, LED16, LED17, LED18, LED19, LED20, LED21, LED22, LED23, LED24, LED25, LED26, LED27, LED28, LED29, LED30, LED31, LED32, LED33, LED34, LED35, LED36, LED37, LED38, LED39, LED40, LED41, LED42, LED43, LED44, LED45, LED46, LED47, LED48, LED49, LED50, LED51, LED52, LED53, LED54, LED55, LED56, LED57, LED58, LED59, LED60, LED61, LED62, LED63, LED64, LED65, LED66, LED67, LED68, LED69, LED70, LED71, LED72, LED73, LED74, LED75, LED76, LED77, LED78, LED79, LED80, LED81, LED82, LED83, LED84, LED85, LED86, LED87, LED88, LED89, LED90, LED91, LED92, LED93, LED94, LED95, LED96, LED97, LED98, LED99, LED100, LED101, LED102, LED103, LED104, LED105, LED106, LED107, LED108: SK6812MINI-E; LED_6028R_NoHoles

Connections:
+5V: C11.2, C12.2, C13.2, C14.2, C15.2, C16.2, C17.2, C18.2, C19.2, C20.2, C21.2, C22.2, C23.2, C24.2, C25.2, C26.2, C27.2, C28.2, C29.1, C30.2, C31.2, C32.2, C33.2, C34.2, C35.2, C36.2, C37.2, C38.2, C39.2, C40.2, C41.2, C42.2, C43.2, C44.2, C45.2, C46.2, C47.2, C48.2, C49.2, C50.2, C51.2, C52.2, C53.2, C54.2, C55.2, C56.2, C57.2, C58.2, C59.2, C60.2, C61.2, C62.2, C63.2, C64.2, C65.2, C66.2, C67.2, C68.2, C69.2, C70.2, C71.2, C72.2, C73.2, C74.2, C75.2, C76.2, C77.2, C78.2, C79.2, C80.2, C81.2, C82.2, C83.2, C84.2, C85.2, C86.2, C87.2, C88.2, C89.2, C90.2, C91.2, C92.2, C93.2, C94.2, C95.2, C96.2, C97.2, C98.2, C99.2, C100.2, C101.2, C102.2, C103.2, C104.2, C105.2, C106.2, C107.2, C108.2, C109.2, C110.2, C111.2, C112.2, C113.2, C114.2, C115.2, C116.2, C117.2, C118.2, LED1.1 (VDD), LED2.1 (VDD), LED3.1 (VDD), LED4.1 (VDD), LED5.1 (VDD), LED6.1 (VDD), LED7.1 (VDD), LED8.1 (VDD), LED9.1 (VDD), LED10.1 (VDD), LED11.1 (VDD), LED12.1 (VDD), LED13.1 (VDD), LED14.1 (VDD), LED15.1 (VDD), LED16.1 (VDD), LED17.1 (VDD), LED18.1 (VDD), LED19.1 (VDD), LED20.1 (VDD), LED21.1 (VDD), LED22.1 (VDD), LED23.1 (VDD), LED24.1 (VDD), LED25.1 (VDD), LED26.1 (VDD), LED27.1 (VDD), LED28.1 (VDD), LED29.1 (VDD), LED30.1 (VDD), LED31.1 (VDD), LED32.1 (VDD), LED33.1 (VDD), LED34.1 (VDD), LED35.1 (VDD), LED36.1 (VDD), LED37.1 (VDD), LED38.1 (VDD), LED39.1 (VDD), LED40.1 (VDD), LED41.1 (VDD), LED42.1 (VDD), LED43.1 (VDD), LED44.1 (VDD), LED45.1 (VDD), LED46.1 (VDD), LED47.1 (VDD), LED48.1 (VDD), LED49.1 (VDD), LED50.1 (VDD), LED51.1 (VDD), LED52.1 (VDD), LED53.1 (VDD), LED54.1 (VDD), LED55.1 (VDD), LED56.1 (VDD), LED57.1 (VDD), LED58.1 (VDD), LED59.1 (VDD), LED60.1 (VDD), LED61.1 (VDD), LED62.1 (VDD), LED63.1 (VDD), LED64.1 (VDD), LED65.1 (VDD), LED66.1 (VDD), LED67.1 (VDD), LED68.1 (VDD), LED69.1 (VDD), LED70.1 (VDD), LED71.1 (VDD), LED72.1 (VDD), LED73.1 (VDD), LED74.1 (VDD), LED75.1 (VDD), LED76.1 (VDD), LED77.1 (VDD), LED78.1 (VDD), LED79.1 (VDD), LED80.1 (VDD), LED81.1 (VDD), LED82.1 (VDD), LED83.1 (VDD), LED84.1 (VDD), LED85.1 (VDD), LED86.1 (VDD), LED87.1 (VDD), LED88.1 (VDD), LED89.1 (VDD), LED90.1 (VDD), LED91.1 (VDD), LED92.1 (VDD), LED93.1 (VDD), LED94.1 (VDD), LED95.1 (VDD), LED96.1 (VDD), LED97.1 (VDD), LED98.1 (VDD), LED99.1 (VDD), LED100.1 (VDD), LED101.1 (VDD), LED102.1 (VDD), LED103.1 (VDD), LED104.1 (VDD), LED105.1 (VDD), LED106.1 (VDD), LED107.1 (VDD), LED108.1 (VDD); also elsewhere on the board
GND: C11.1, C12.1, C13.1, C14.1, C15.1, C16.1, C17.1, C18.1, C19.1, C20.1, C21.1, C22.1, C23.1, C24.1, C25.1, C26.1, C27.1, C28.1, C29.2, C30.1, C31.1, C32.1, C33.1, C34.1, C35.1, C36.1, C37.1, C38.1, C39.1, C40.1, C41.1, C42.1, C43.1, C44.1, C45.1, C46.1, C47.1, C48.1, C49.1, C50.1, C51.1, C52.1, C53.1, C54.1, C55.1, C56.1, C57.1, C58.1, C59.1, C60.1, C61.1, C62.1, C63.1, C64.1, C65.1, C66.1, C67.1, C68.1, C69.1, C70.1, C71.1, C72.1, C73.1, C74.1, C75.1, C76.1, C77.1, C78.1, C79.1, C80.1, C81.1, C82.1, C83.1, C84.1, C85.1, C86.1, C87.1, C88.1, C89.1, C90.1, C91.1, C92.1, C93.1, C94.1, C95.1, C96.1, C97.1, C98.1, C99.1, C100.1, C101.1, C102.1, C103.1, C104.1, C105.1, C106.1, C107.1, C108.1, C109.1, C110.1, C111.1, C112.1, C113.1, C114.1, C115.1, C116.1, C117.1, C118.1, LED1.4 (VSS), LED2.4 (VSS), LED3.4 (VSS), LED4.4 (VSS), LED5.4 (VSS), LED6.4 (VSS), LED7.4 (VSS), LED8.4 (VSS), LED9.4 (VSS), LED10.4 (VSS), LED11.4 (VSS), LED12.4 (VSS), LED13.4 (VSS), LED14.4 (VSS), LED15.4 (VSS), LED16.4 (VSS), LED17.4 (VSS), LED18.4 (VSS), LED19.4 (VSS), LED20.4 (VSS), LED21.4 (VSS), LED22.4 (VSS), LED23.4 (VSS), LED24.4 (VSS), LED25.4 (VSS), LED26.4 (VSS), LED27.4 (VSS), LED28.4 (VSS), LED29.4 (VSS), LED30.4 (VSS), LED31.4 (VSS), LED32.4 (VSS), LED33.4 (VSS), LED34.4 (VSS), LED35.4 (VSS), LED36.4 (VSS), LED37.4 (VSS), LED38.4 (VSS), LED39.4 (VSS), LED40.4 (VSS), LED41.4 (VSS), LED42.4 (VSS), LED43.4 (VSS), LED44.4 (VSS), LED45.4 (VSS), LED46.4 (VSS), LED47.4 (VSS), LED48.4 (VSS), LED49.4 (VSS), LED50.4 (VSS), LED51.4 (VSS), LED52.4 (VSS), LED53.4 (VSS), LED54.4 (VSS), LED55.4 (VSS), LED56.4 (VSS), LED57.4 (VSS), LED58.4 (VSS), LED59.4 (VSS), LED60.4 (VSS), LED61.4 (VSS), LED62.4 (VSS), LED63.4 (VSS), LED64.4 (VSS), LED65.4 (VSS), LED66.4 (VSS), LED67.4 (VSS), LED68.4 (VSS), LED69.4 (VSS), LED70.4 (VSS), LED71.4 (VSS), LED72.4 (VSS), LED73.4 (VSS), LED74.4 (VSS), LED75.4 (VSS), LED76.4 (VSS), LED77.4 (VSS), LED78.4 (VSS), LED79.4 (VSS), LED80.4 (VSS), LED81.4 (VSS), LED82.4 (VSS), LED83.4 (VSS), LED84.4 (VSS), LED85.4 (VSS), LED86.4 (VSS), LED87.4 (VSS), LED88.4 (VSS), LED89.4 (VSS), LED90.4 (VSS), LED91.4 (VSS), LED92.4 (VSS), LED93.4 (VSS), LED94.4 (VSS), LED95.4 (VSS), LED96.4 (VSS), LED97.4 (VSS), LED98.4 (VSS), LED99.4 (VSS), LED100.4 (VSS), LED101.4 (VSS), LED102.4 (VSS), LED103.4 (VSS), LED104.4 (VSS), LED105.4 (VSS), LED106.4 (VSS), LED107.4 (VSS), LED108.4 (VSS); also elsewhere on the board
LED: LED19.3 (DIN); also elsewhere on the board
unnamed: LED1.3 (DIN), LED2.2 (DOUT)
unnamed: LED1.2 (DOUT), LED20.3 (DIN)
unnamed: LED2.3 (DIN), LED3.2 (DOUT)
unnamed: LED3.3 (DIN), LED4.2 (DOUT)
unnamed: LED4.3 (DIN), LED5.2 (DOUT)
unnamed: LED5.3 (DIN), LED6.2 (DOUT)
unnamed: LED6.3 (DIN), LED7.2 (DOUT)
unnamed: LED7.3 (DIN), LED8.2 (DOUT)
unnamed: LED8.3 (DIN), LED9.2 (DOUT)
unnamed: LED10.3 (DIN), LED11.2 (DOUT)
unnamed: LED9.3 (DIN), LED10.2 (DOUT)
unnamed: LED11.3 (DIN), LED12.2 (DOUT)
unnamed: LED12.3 (DIN), LED13.2 (DOUT)
unnamed: LED13.3 (DIN), LED14.2 (DOUT)
unnamed: LED14.3 (DIN), LED15.2 (DOUT)
unnamed: LED15.3 (DIN), LED16.2 (DOUT)
unnamed: LED16.3 (DIN), LED17.2 (DOUT)
unnamed: LED17.3 (DIN), LED18.2 (DOUT)
unnamed: LED18.3 (DIN), LED19.2 (DOUT)
unnamed: LED20.2 (DOUT), LED21.3 (DIN)
unnamed: LED21.2 (DOUT), LED22.3 (DIN)
unnamed: LED22.2 (DOUT), LED23.3 (DIN)
unnamed: LED23.2 (DOUT), LED24.3 (DIN)
unnamed: LED24.2 (DOUT), LED25.3 (DIN)
unnamed: LED25.2 (DOUT), LED26.3 (DIN)
unnamed: LED26.2 (DOUT), LED27.3 (DIN)
unnamed: LED27.2 (DOUT), LED28.3 (DIN)
unnamed: LED28.2 (DOUT), LED29.3 (DIN)
unnamed: LED29.2 (DOUT), LED30.3 (DIN)
unnamed: LED30.2 (DOUT), LED31.3 (DIN)
unnamed: LED31.2 (DOUT), LED32.3 (DIN)
unnamed: LED32.2 (DOUT), LED33.3 (DIN)
unnamed: LED33.2 (DOUT), LED34.3 (DIN)
unnamed: LED34.2 (DOUT), LED35.3 (DIN)
unnamed: LED35.2 (DOUT), LED36.3 (DIN)
unnamed: LED36.2 (DOUT), LED37.3 (DIN)
unnamed: LED37.2 (DOUT), LED38.3 (DIN)
unnamed: LED38.2 (DOUT), LED39.3 (DIN)
unnamed: LED39.2 (DOUT), LED40.3 (DIN)
unnamed: LED40.2 (DOUT), LED61.3 (DIN)
unnamed: LED41.3 (DIN), LED42.2 (DOUT)
unnamed: LED41.2 (DOUT), LED62.3 (DIN)
unnamed: LED42.3 (DIN), LED43.2 (DOUT)
unnamed: LED43.3 (DIN), LED44.2 (DOUT)
unnamed: LED44.3 (DIN), LED45.2 (DOUT)
unnamed: LED45.3 (DIN), LED46.2 (DOUT)
unnamed: LED46.3 (DIN), LED47.2 (DOUT)
unnamed: LED47.3 (DIN), LED48.2 (DOUT)
unnamed: LED48.3 (DIN), LED49.2 (DOUT)
unnamed: LED49.3 (DIN), LED50.2 (DOUT)
unnamed: LED50.3 (DIN), LED51.2 (DOUT)
unnamed: LED51.3 (DIN), LED52.2 (DOUT)
unnamed: LED52.3 (DIN), LED53.2 (DOUT)
unnamed: LED53.3 (DIN), LED54.2 (DOUT)
unnamed: LED54.3 (DIN), LED55.2 (DOUT)
unnamed: LED55.3 (DIN), LED56.2 (DOUT)
unnamed: LED56.3 (DIN), LED57.2 (DOUT)
unnamed: LED57.3 (DIN), LED58.2 (DOUT)
unnamed: LED58.3 (DIN), LED59.2 (DOUT)
unnamed: LED59.3 (DIN), LED60.2 (DOUT)
unnamed: LED60.3 (DIN), LED61.2 (DOUT)
unnamed: LED62.2 (DOUT), LED63.3 (DIN)
unnamed: LED63.2 (DOUT), LED64.3 (DIN)
unnamed: LED64.2 (DOUT), LED65.3 (DIN)
unnamed: LED65.2 (DOUT), LED66.3 (DIN)
unnamed: LED66.2 (DOUT), LED67.3 (DIN)
unnamed: LED67.2 (DOUT), LED68.3 (DIN)
unnamed: LED68.2 (DOUT), LED69.3 (DIN)
unnamed: LED69.2 (DOUT), LED70.3 (DIN)
unnamed: LED70.2 (DOUT), LED71.3 (DIN)
unnamed: LED71.2 (DOUT), LED72.3 (DIN)
unnamed: LED72.2 (DOUT), LED73.3 (DIN)
unnamed: LED73.2 (DOUT), LED74.3 (DIN)
unnamed: LED74.2 (DOUT), LED75.3 (DIN)
unnamed: LED75.2 (DOUT), LED76.3 (DIN)
unnamed: LED76.2 (DOUT), LED77.3 (DIN)
unnamed: LED77.2 (DOUT), LED95.3 (DIN)
unnamed: LED78.3 (DIN), LED79.2 (DOUT)
unnamed: LED78.2 (DOUT), LED96.3 (DIN)
unnamed: LED79.3 (DIN), LED80.2 (DOUT)
unnamed: LED80.3 (DIN), LED81.2 (DOUT)
unnamed: LED81.3 (DIN), LED82.2 (DOUT)
unnamed: LED82.3 (DIN), LED83.2 (DOUT)
unnamed: LED83.3 (DIN), LED84.2 (DOUT)
unnamed: LED84.3 (DIN), LED85.2 (DOUT)
unnamed: LED85.3 (DIN), LED86.2 (DOUT)
unnamed: LED86.3 (DIN), LED87.2 (DOUT)
unnamed: LED87.3 (DIN), LED88.2 (DOUT)
unnamed: LED88.3 (DIN), LED89.2 (DOUT)
unnamed: LED89.3 (DIN), LED90.2 (DOUT)
unnamed: LED90.3 (DIN), LED91.2 (DOUT)
unnamed: LED91.3 (DIN), LED92.2 (DOUT)
unnamed: LED92.3 (DIN), LED93.2 (DOUT)
unnamed: LED93.3 (DIN), LED94.2 (DOUT)
unnamed: LED94.3 (DIN), LED95.2 (DOUT)
unnamed: LED96.2 (DOUT), LED97.3 (DIN)
unnamed: LED97.2 (DOUT), LED98.3 (DIN)
unnamed: LED98.2 (DOUT), LED99.3 (DIN)
unnamed: LED99.2 (DOUT), LED100.3 (DIN)
unnamed: LED100.2 (DOUT), LED101.3 (DIN)
unnamed: LED101.2 (DOUT), LED102.3 (DIN)
unnamed: LED102.2 (DOUT), LED103.3 (DIN)
unnamed: LED103.2 (DOUT), LED104.3 (DIN)
unnamed: LED104.2 (DOUT), LED105.3 (DIN)
unnamed: LED105.2 (DOUT), LED106.3 (DIN)
unnamed: LED106.2 (DOUT), LED107.3 (DIN)
unnamed: LED107.2 (DOUT), LED108.3 (DIN)

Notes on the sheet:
This file contains the LED chain

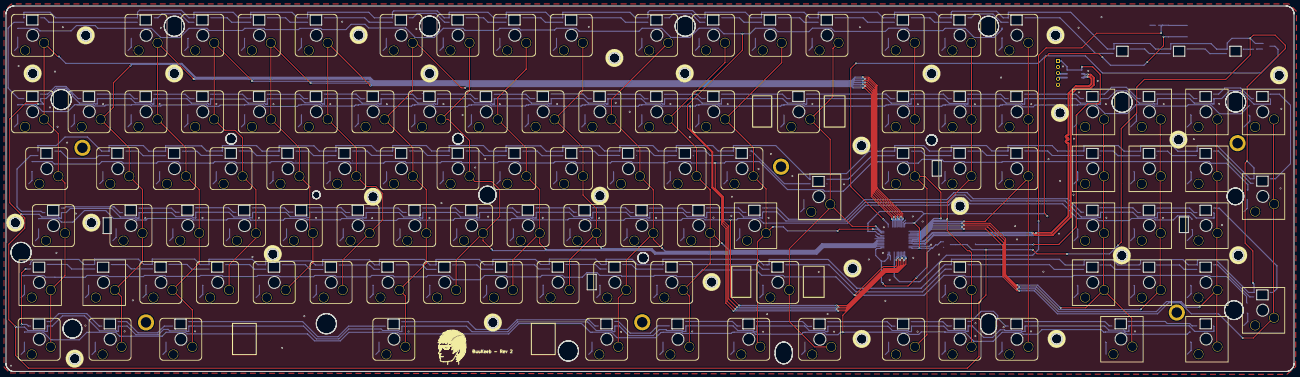
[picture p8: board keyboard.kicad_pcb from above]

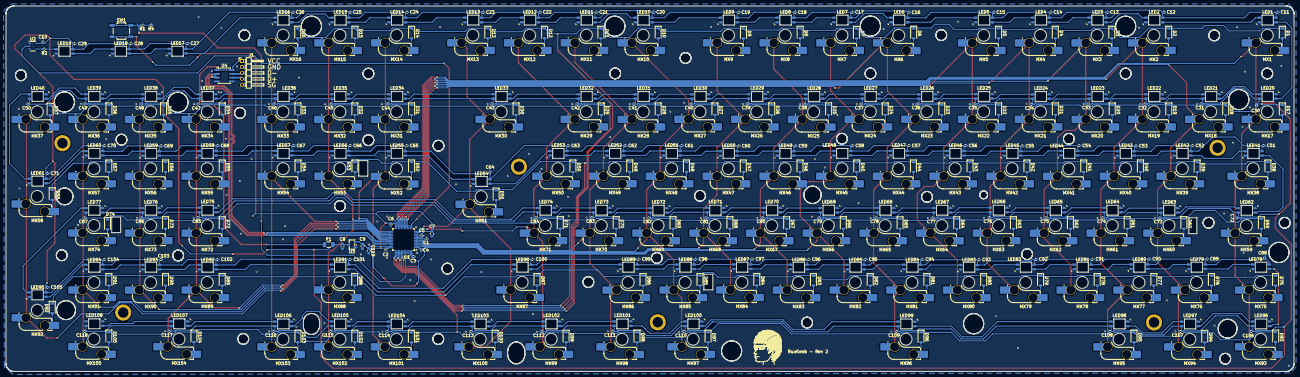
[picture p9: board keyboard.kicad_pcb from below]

Board: 2 copper layers, 431.0 x 122.3 mm, 453 parts (447 on the bottom side), 253 nets.

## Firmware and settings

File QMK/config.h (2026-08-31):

// Comment this define to "overclock" the direct mode LEDs
// I will not be responsible for wrecked boards!
#define LIMIT_DIRECTMODE_BRIGHTNESS

#define WS2812_PWM_DRIVER PWMD15
#define WS2812_PWM_CHANNEL 2
#define WS2812_PWM_PAL_MODE 0
#define WS2812_PWM_DMA_STREAM STM32_DMA1_STREAM5
#define WS2812_PWM_DMA_CHANNEL 5

#define EECONFIG_USER_DATA_SIZE 324
#define EECONFIG_USER_DATA_VERSION 324

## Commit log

2026-07-20 Publish for Review
    [KeyboardMatrix.kicad_sch, LEDChain.kicad_sch, keyboard.kicad_sch]
2026-07-20 Fixed some 45º traces
2026-07-23 BigBass recommended changes + more thanks
    [keyboard.kicad_sch]
2026-07-26 Big round of changes. Click to read more.
    - Labels on the MCU have been switched around to make routing nicer
    - ESD Chip is now right next to the connector
    - All 3.3V inputs have the 100nF capacitor correctly placed next to it
    - VDDA has an extra 10uF capacitor (as per the STM32 spec sheet)
    - The start of the 3.3V rail has a 4.7uF capacitor (as per the STM32 spec sheet)
    - All LEDs now have a 100nF capacitor connected to it, and a 100ohm resistor at the start of the data line
    - LED data line has been level shifted to 5V
    [LEDChain.kicad_sch, keyboard.kicad_pcb, keyboard.kicad_sch]
2026-07-26 Added useful relevant schematic PDFs
2026-07-26 Differential pair length tweak
    [keyboard.kicad_pcb]
2026-07-26 Simplified key routing
    [keyboard.kicad_pcb, keyboard.kicad_sch]
2026-07-26 Keyboard wiring simplifcations + schematic editor warning fixes
    [KeyboardMatrix.kicad_sch, LEDChain.kicad_sch, keyboard.kicad_pcb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]
2026-07-27 Made power rails thicker
    [keyboard.kicad_pcb]
2026-07-27 Minor line tweaks and prepping for gerbers
    [keyboard.kicad_pcb, keyboard.kicad_sch]
2026-07-27 Better LED 5V rail setup and matrix wiring
    [keyboard.kicad_pcb, keyboard.kicad_sch]
2026-07-27 JLCPCB production files and BOM
    [bom-JLCPCB Assembly Order.xls, bom.csv, designators.csv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]
2026-07-28 USB differential pair mistake correction. Oh dear. Guess this is the start of Rev 2 now.
    [KeyboardMatrix.kicad_sch, keyboard.kicad_pcb, keyboard.kicad_sch]
2026-08-15 Revision 2
    [KeyboardMatrix.kicad_sch, LEDChain.kicad_sch, bom-JLCPCB Assembly Order.xls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]
2026-08-31 Fixed Indicator LEDs not using effect color properly
